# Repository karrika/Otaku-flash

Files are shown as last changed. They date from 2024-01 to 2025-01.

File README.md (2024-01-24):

# Otaku-flash
A single game flash card for Atari 2600, Atari 7800 and Atari 2600+

The logic in this card is based on Raspberrypi Pico
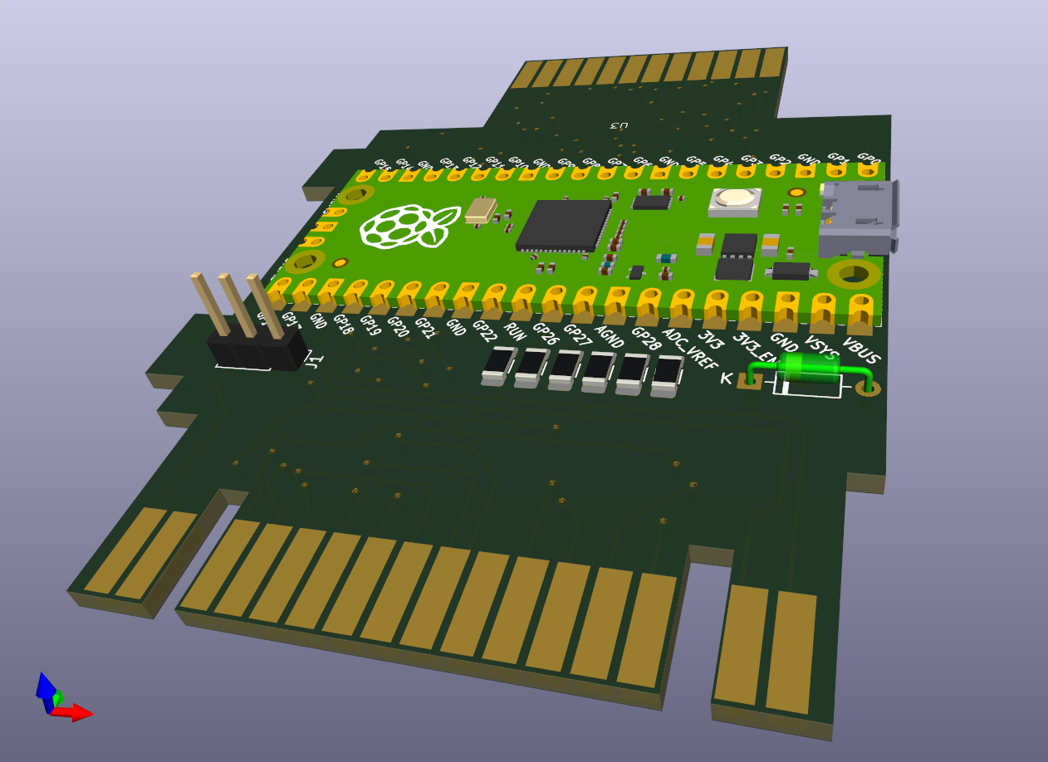
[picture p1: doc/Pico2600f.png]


The startup of the Pico is too slow for a real Atari 7800. The way I
run the game is by:
- inserting the card when the power is off
- then I connect a powerbank to Pico's USB socket
- finally I power on the console
This allows the Pico to prepare everything before I power on
my Atari 7800 console. The schottky diode in the cart prevents the
powerbank to power on the console when the cart has power but the
console has not.

The new Atari 2600+ does not have a startup problem. But the Otaku cart
may draw too much current so I am also using the powerbank when the cart
is in the 2600+.

The cart has a 2600 connector and a 7800 connector. The 7800 connector can
be used for running all games. The 2600 connector only works for 2600 games.

Programming the cart:
- keep the button pressed while inserting the USB cable to the PC
- release the button
- drag a a game.uf2 file to the folder opened by the Otaku card

For converting a game into the uf2 format you need to install Raspberry Pico
tools with the SDK kit.

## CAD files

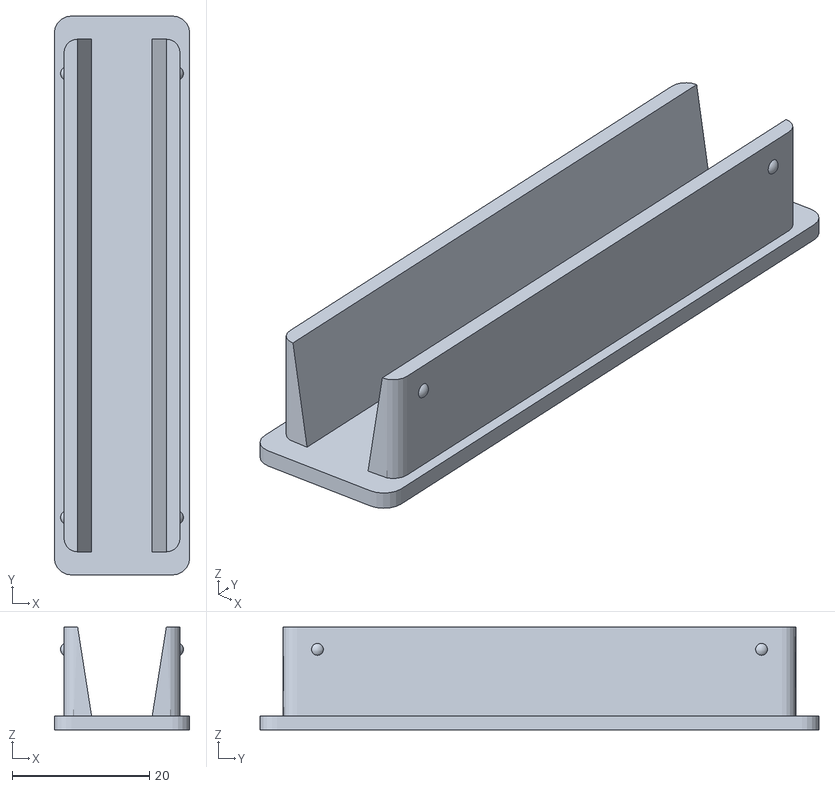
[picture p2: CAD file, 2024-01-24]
Otaku Flash Top2.stl
19.8 x 81.5 x 15.0

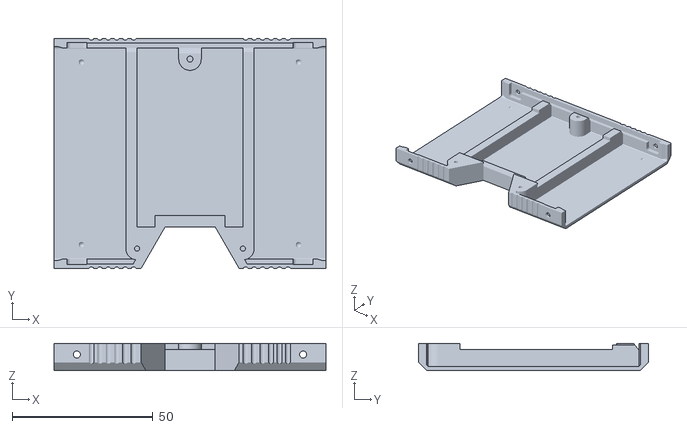
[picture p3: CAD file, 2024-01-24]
Otaku Flash Cart Bottom2.stl
96.5 x 81.5 x 9.75

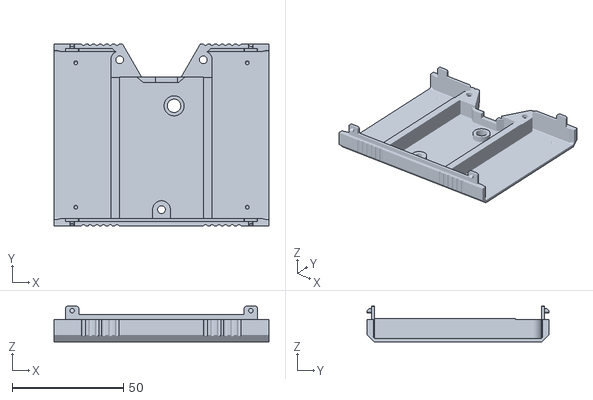
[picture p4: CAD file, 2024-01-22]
Otaku Flash Cart Top.stl
96.5 x 81.5 x 16.0

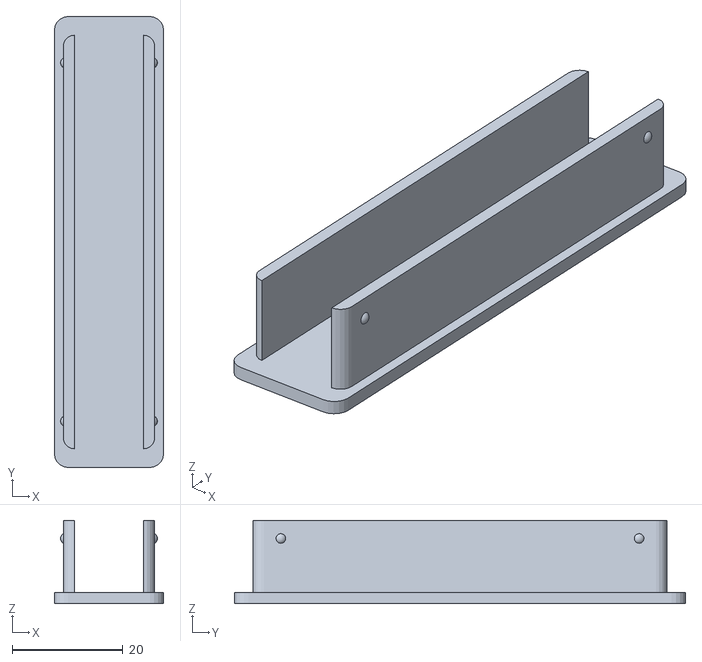
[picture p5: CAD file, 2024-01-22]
Otaku Flash Cart Cover.stl
19.8 x 81.5 x 15.0

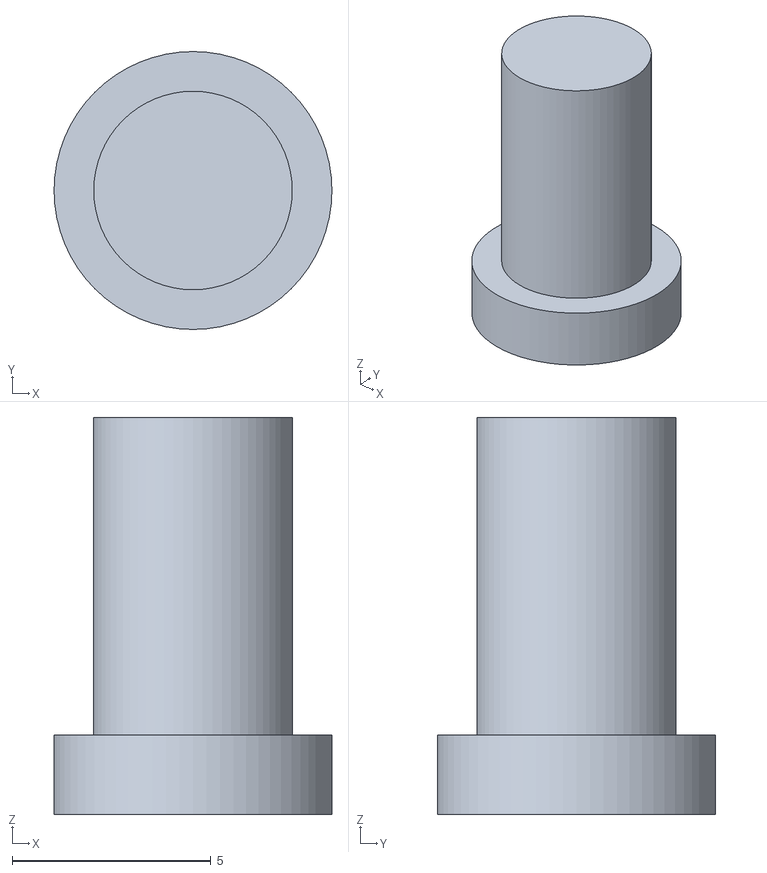
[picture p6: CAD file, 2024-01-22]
Otaku Flash Cart Button.stl
7.00 x 7.00 x 10.0

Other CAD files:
Otaku Flash Cart Bottom.stl
Otaku.blend

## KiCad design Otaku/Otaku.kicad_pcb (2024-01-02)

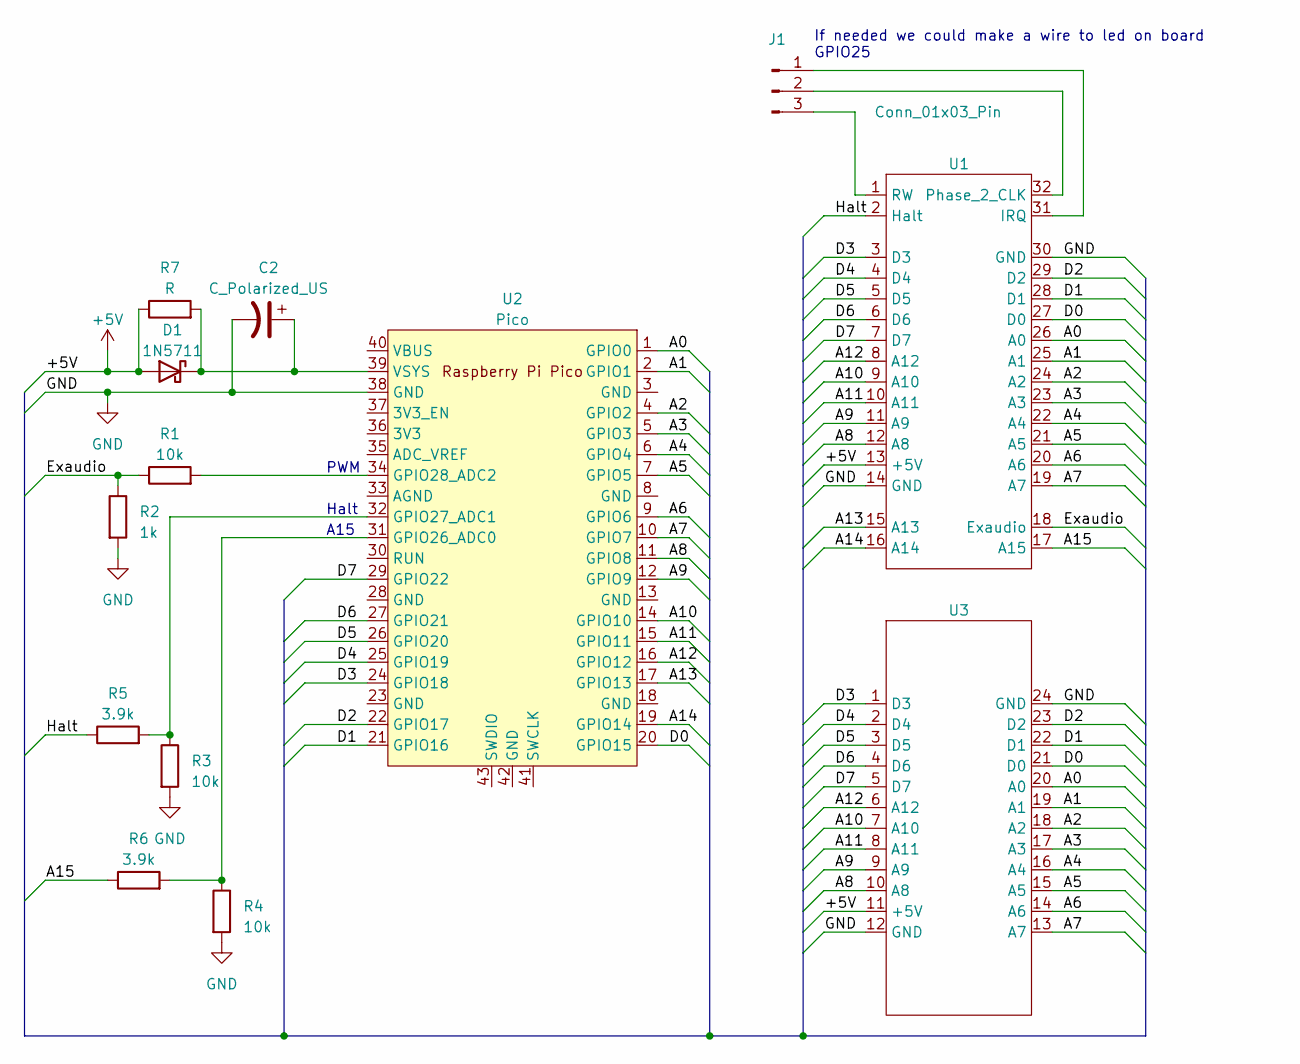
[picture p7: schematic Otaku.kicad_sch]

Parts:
C2: C_Polarized_US; CP_Axial_L10.0mm_D4.5mm_P15.00mm_Horizontal
D1: 1N5711; D_DO-35_SOD27_P7.62mm_Horizontal
J1: Conn_01x03_Pin; PinHeader_1x03_P2.54mm_Vertical
R1, R3, R4: 10k; R_1206_3216Metric_Pad1.30x1.75mm_HandSolder
R2: 1k; R_1206_3216Metric_Pad1.30x1.75mm_HandSolder
R5, R6: 3.9k; R_1206_3216Metric_Pad1.30x1.75mm_HandSolder
R7: R; R_1206_3216Metric_Pad1.30x1.75mm_HandSolder
U1: A7800
U2: Pico; RPi_Pico_SMD_TH
U3: A2600

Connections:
+5V: D1.2 (A), R7.1, U1.13 (+5V), U3.11 (+5V)
/A0: U1.26 (A0), U2.1 (GPIO0), U3.20 (A0)
/A1: U1.25 (A1), U2.2 (GPIO1), U3.19 (A1)
/A2: U1.24 (A2), U2.4 (GPIO2), U3.18 (A2)
/A3: U1.23 (A3), U2.5 (GPIO3), U3.17 (A3)
/A4: U1.22 (A4), U2.6 (GPIO4), U3.16 (A4)
/A5: U1.21 (A5), U2.7 (GPIO5), U3.15 (A5)
/A6: U1.20 (A6), U2.9 (GPIO6), U3.14 (A6)
/A7: U1.19 (A7), U2.10 (GPIO7), U3.13 (A7)
/A8: U1.12 (A8), U2.11 (GPIO8), U3.10 (A8)
/A9: U1.11 (A9), U2.12 (GPIO9), U3.9 (A9)
/A10: U1.9 (A10), U2.14 (GPIO10), U3.7 (A10)
/A11: U1.10 (A11), U2.15 (GPIO11), U3.8 (A11)
/A12: U1.8 (A12), U2.16 (GPIO12), U3.6 (A12)
/A13: U1.15 (A13), U2.17 (GPIO13)
/A14: U1.16 (A14), U2.19 (GPIO14)
/A15: R6.1, U1.17 (A15)
/D0: U1.27 (D0), U2.20 (GPIO15), U3.21 (D0)
/D1: U1.28 (D1), U2.21 (GPIO16), U3.22 (D1)
/D2: U1.29 (D2), U2.22 (GPIO17), U3.23 (D2)
/D3: U1.3 (D3), U2.24 (GPIO18), U3.1 (D3)
/D4: U1.4 (D4), U2.25 (GPIO19), U3.2 (D4)
/D5: U1.5 (D5), U2.26 (GPIO20), U3.3 (D5)
/D6: U1.6 (D6), U2.27 (GPIO21), U3.4 (D6)
/D7: U1.7 (D7), U2.29 (GPIO22), U3.5 (D7)
/Exaudio: R1.1, R2.1, U1.18 (Exaudio)
/Halt: R5.1, U1.2 (Halt)
GND: C2.2, R2.2, R3.2, R4.2, U1.14 (GND), U1.30 (GND), U2.38 (GND), U3.12 (GND), U3.24 (GND)
unnamed: C2.1, D1.1 (K), R7.2, U2.39 (VSYS)
unnamed: J1.1, U1.31 (IRQ)
unnamed: J1.2, U1.32 (Phase_2_CLK)
unnamed: J1.3, U1.1 (RW)
unnamed: R4.1, R6.2, U2.31 (GPIO26_ADC0)
unnamed: R3.1, R5.2, U2.32 (GPIO27_ADC1)
unnamed: R1.2, U2.34 (GPIO28_ADC2)

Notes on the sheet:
PWM
A15
Halt
If needed we could make a wire to led on board GPIO25

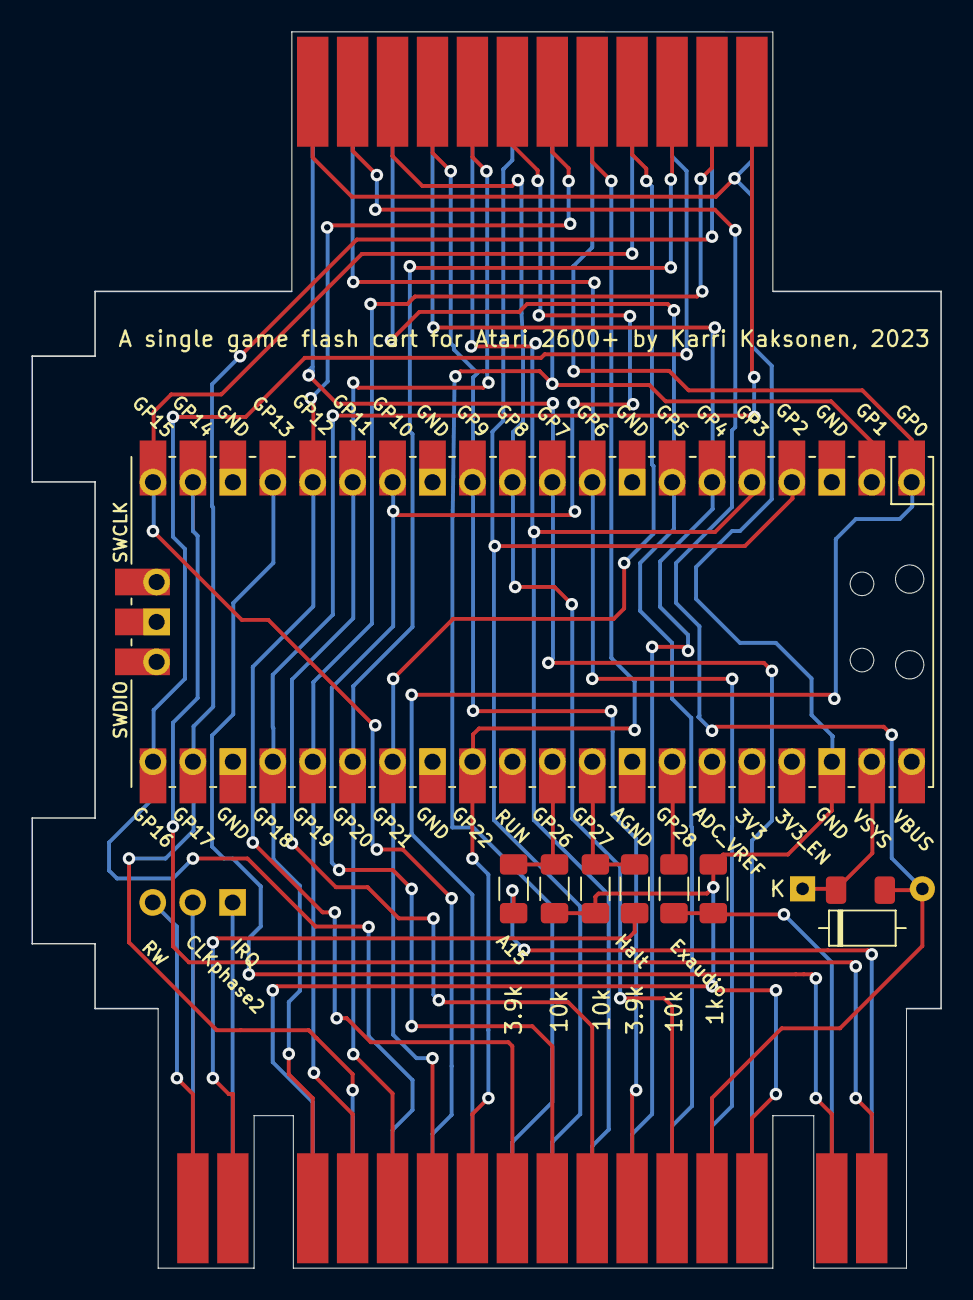
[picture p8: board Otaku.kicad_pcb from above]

Board: 2 copper layers, 57.8 x 78.6 mm, 12 parts (0 on the bottom side), 35 nets.

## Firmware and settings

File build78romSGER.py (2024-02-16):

import sys

class rom:
    def __init__(self, fname):
        with open(fname, 'rb') as f:
            self.raw = f.read()
            if len(self.raw) % 1024 == 128:
                self.data = self.raw[128:]
            else:
                self.data = self.raw

    def writedata(self, f):
        code = '''
/*
* Otaku-flash
* Simulate an SuperGame with EXRAM Atari 7800 ROM chip with a
* Raspberry Pi Pico.
*
* Last 16k bank 7 at C000 is fixed
* There is also a 16k RAM bank at 4000
* a write to area 8000-BFFF chooses the 16k bank for the 8000 area
*
* Karri Kaksonen, 2024
* based on work by
* Nick Bild 2021
*/

#include "pico/stdlib.h"
#include "hardware/clocks.h"
#include "hardware/vreg.h"
#include "pin_definitions.h"
#include <string.h>

'''
        f.write(code)
        f.write('#define ROM_SIZE ' + "0x{:x}".format(len(self.data)) + '\n')
        f.write('#define BANKS ' + "0x{:x}".format(int(len(self.data) / 16384)) + '\n')
        f.write('\n')
        f.write('const uint8_t game_contents[ROM_SIZE] __attribute__ ((aligned(ROM_SIZE))) = {\n')
        for i in range(0, len(self.data), 8):
            f.write('    ')
            for j in range(7):
                f.write("0x{:02x}".format(self.data[i + j]) + ', ')
            if i + 7 < len(self.data) - 1:
                f.write("0x{:02x}".format(self.data[i + 7]) + ',\n')
            else:
                f.write("0x{:02x}".format(self.data[i + 7]))
        f.write('};\n')
        f.write('\n')
        if len(self.data) <= 128 * 1024:
            code = '''
uint8_t ram_contents[ROM_SIZE] __attribute__ ((aligned(0x10000))) = {};
uint8_t exram_contents[0x4000] __attribute__ ((aligned(0x100))) = {};

int main() {
    uint32_t rawaddr;
    uint32_t addr;
    uint32_t bank;
    uint8_t newbank;
    uint8_t rom_in_use;
    uint8_t readwrite;

    // Specify contents of emulated ROM.
    memcpy(ram_contents, game_contents, ROM_SIZE);
    rom_in_use = 1;
    // Set default bank
    bank = 0;

    // Set system clock speed.
    // 400 MHz
    vreg_set_voltage(VREG_VOLTAGE_1_30);
    set_sys_clock_pll(1600000000, 4, 1);
    
    // GPIO setup.
    gpio_init_mask(0xe7fffff);         // All pins.
    gpio_set_dir_in_masked(0xe007fff); // Address and RW pins.
    gpio_set_dir_out_masked(0x7f8000); // Data pins.
    gpio_set_function(A15, GPIO_FUNC_NULL);
    gpio_set_function(RW, GPIO_FUNC_NULL);
    
    // Continually check address lines and
    // put associated data on bus.
    while (true) {
        // Get address
        rawaddr = gpio_get_all();
        addr = rawaddr & 0x7fff;
        // Check for A15
        if (rawaddr & 0x4000000) {
            // Check for A14
            if (addr & 0x4000) {
                // Set the data on the bus for fixed bank 7
                gpio_put_masked(0x7f8000, ram_contents[addr + ROM_SIZE - 0x8000] << 15);
                rawaddr = gpio_get_all() & 0x6004000;
	        if (rawaddr == 0x6004000) {
                    // Read cycle
                    if (!rom_in_use) {
                        gpio_set_dir_out_masked(0x7f8000);
                        rom_in_use = 1;
                    }
                }
            } else {
                // Set the data on the bus for active bank
                gpio_put_masked(0x7f8000, ram_contents[addr + bank] << 15);
                // Check for RW
                rawaddr = gpio_get_all() & 0x6004000;
	        if (rawaddr == 0x6000000) {
                    // Read cycle
                    if (!rom_in_use) {
                        gpio_set_dir_out_masked(0x7f8000);
                        rom_in_use = 1;
                    }
                } else {
                    // Write cycle to ROM
                    rawaddr = gpio_get_all() & 0x6000000;
                    // Check for bankswitch
                    if (rawaddr == 0x4000000) {
                        // Bankswitching write
                        gpio_set_dir_in_masked(0x7f8000);
                        rawaddr = gpio_get_all();
                        newbank = (rawaddr >> 15) & 0xff;
                        if (newbank < BANKS) {
                            bank = newbank * 0x4000;
                        }
                        rom_in_use = 0;
                    }
                }
            }
        } else {
            rawaddr = gpio_get_all();
            // EXRAM at 0x4000
            if (rawaddr & 0x4000) {
                addr = rawaddr & 0x3fff;
                gpio_put_masked(0x7f8000, exram_contents[addr] << 15);
                rawaddr = gpio_get_all() & 0x6004000;
	        if (rawaddr == 0x2004000) {
                    // Read cycle
                    if (!rom_in_use) {
                        gpio_set_dir_out_masked(0x7f8000);
                        rom_in_use = 1;
                    }
                } else {
	            if (rawaddr == 0x0004000) {
                        // Write cycle
                        gpio_set_dir_in_masked(0x7f8000);
                        rawaddr = gpio_get_all();
                        exram_contents[rawaddr & 0x3fff] = (rawaddr >> 15) & 0xff;
                        rom_in_use = 0;
                    } else {
                        if (rom_in_use) {
                            gpio_set_dir_in_masked(0x7f8000);
                            rom_in_use = 0;
                        }
                    }
                }
            } else {
                if (rom_in_use) {
                    gpio_set_dir_in_masked(0x7f8000);
                    rom_in_use = 0;
                }
            }
        }
    }
}

'''
        else:
            code = '''
uint8_t exram_contents[0x4000] __attribute__ ((aligned(0x100))) = {};

int main() {
    uint32_t oldrawaddr;
    uint32_t rawaddr;
    uint32_t addr;
    uint32_t bank;
    uint8_t newbank;
    uint8_t rom_in_use;
    uint8_t readwrite;

    // Specify contents of emulated ROM.
    rom_in_use = 1;
    // Set default bank
    bank = 0;

    // Set system clock speed.
    // 400 MHz
    vreg_set_voltage(VREG_VOLTAGE_1_30);
    set_sys_clock_pll(1600000000, 4, 1);
    
    // GPIO setup.
    gpio_init_mask(0xe7fffff);         // All pins.
    gpio_set_dir_in_masked(0xe007fff); // Address and RW pins.
    gpio_set_dir_out_masked(0x7f8000); // Data pins.
    gpio_set_function(A15, GPIO_FUNC_NULL);
    gpio_set_function(RW, GPIO_FUNC_NULL);
    
    // Continually check address lines and
    // put associated data on bus.
    while (true) {
        // Get address
        rawaddr = gpio_get_all();
        addr = rawaddr & 0x7fff;
        // Check for A15
        if (rawaddr & 0x4000000) {
            // Check for A14
            if (addr & 0x4000) {
                // Set the data on the bus for fixed bank 7
                gpio_put_masked(0x7f8000, game_contents[addr + ROM_SIZE - 0x8000] << 15);
                rawaddr = gpio_get_all() & 0x6004000;
	        if (rawaddr == 0x6004000) {
                    // Read cycle
                    if (!rom_in_use) {
                        gpio_set_dir_out_masked(0x7f8000);
                        rom_in_use = 1;
                    }
                }
            } else {
                // Set the data on the bus for active bank
                gpio_put_masked(0x7f8000, game_contents[addr + bank] << 15);
                // Check for RW
                rawaddr = gpio_get_all() & 0x6004000;
	        if (rawaddr == 0x6000000) {
                    // Read cycle
                    if (!rom_in_use) {
                        gpio_set_dir_out_masked(0x7f8000);
                        rom_in_use = 1;
                    }
                } else {
                    // Write cycle to ROM
                    rawaddr = gpio_get_all() & 0x6000000;
                    // Check for bankswitch
                    if (rawaddr == 0x4000000) {
                        // Bankswitching write
                        gpio_set_dir_in_masked(0x7f8000);
                        rawaddr = gpio_get_all();
                        newbank = (rawaddr >> 15) & 0xff;
                        if (newbank < BANKS) {
                            bank = newbank * 0x4000;
                        }
                        rom_in_use = 0;
                    }
                }
            }
        } else {
            rawaddr = gpio_get_all();
            // EXRAM at 0x4000
            if (rawaddr & 0x4000) {
                addr = rawaddr & 0x3fff;
                gpio_put_masked(0x7f8000, exram_contents[addr] << 15);
                rawaddr = gpio_get_all() & 0x6004000;
	        if (rawaddr == 0x2004000) {
                    // Read cycle
                    if (!rom_in_use) {
                        gpio_set_dir_out_masked(0x7f8000);
                        rom_in_use = 1;
                    }
                } else {
	            if (rawaddr == 0x0004000) {
                        // Write cycle
                        gpio_set_dir_in_masked(0x7f8000);
                        rawaddr = gpio_get_all();
                        exram_contents[rawaddr & 0x3fff] = (rawaddr >> 15) & 0xff;
                        rom_in_use = 0;
                    } else {
                        if (rom_in_use) {
                            gpio_set_dir_in_masked(0x7f8000);
                            rom_in_use = 0;
                        }
                    }
                }
            } else {
                if (rom_in_use) {
                    gpio_set_dir_in_masked(0x7f8000);
                    rom_in_use = 0;
                }
            }
        }
    }
}

'''
        f.write(code)

if __name__ == '__main__':
    fname=str(sys.argv[len(sys.argv)-1])
    r = rom(fname)
    fname = 'rom.c'
    f = open(fname, 'w')
    r.writedata(f)
    f.close()

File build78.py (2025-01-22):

import sys
import subprocess
import build78rom8k
import build78rom16k
import build78rom32k
import build78rom48k
import build78romAB
import build78romSG
import build78romSGEF
import build78romSGER
import build78romSGERP450
import build78romSGERYMP450

class rom:
    def __init__(self, fname):
        self.fname = fname

    def carttype(self):
        self.type = b'Not supported'
        with open(self.fname, 'rb') as f:
            data = f.read()
        self.header = data[:128]
        self.version = self.header[0]
        print('Version:', self.version)
        self.name = str(self.header[17:49], 'utf-8')
        print('Name:', self.name)
        self.size = int.from_bytes(self.header[49:53], 'big')
        print('Size:', self.size)
        if self.size == 8192:
            self.type = b'8K'
        elif self.size == 16384:
            self.type = b'16K'
        elif self.size == 32768:
            self.type = b'32K'
        elif self.size == 49152:
            self.type = b'48K'
        self.CartType = []
        self.typeA = self.header[53]
        self.typeB = self.header[54]
        if self.typeB & 2:
            self.CartType.append('SUPER')
            self.type = b'SG'
        if self.typeB & 16:
            self.CartType.append('EXFIX')
            if self.type == b'SG':
                self.type = b'SGEF'
            else:
                self.type = b'Not supported'
        if self.typeB & 4:
            self.CartType.append('EXRAM')
            if self.type == b'SG':
                self.type = b'SGER'
            else:
                self.type = b'Not supported'
        if self.typeA & 32:
            self.CartType.append('BANKSET')
            self.type = b'Not supported'
        if self.typeA & 16:
            self.CartType.append('SOUPER')
            self.type = b'Not supported'
        if self.typeA & 2:
            self.CartType.append('ABSOLUTE')
            self.type = b'AB'
            print(self.type)
        if self.typeA & 64:
            self.CartType.append('EXRAM/M2')
            self.type = b'Not supported'
        if self.typeB & 8:
            self.CartType.append('EXROM')
            self.type = b'Not supported'
        if self.typeA & 128:
            self.CartType.append('POKEY @0800')
            self.type = b'Not supported'
        if self.typeA & 8:
            self.CartType.append('YM2151 @0461')
            if self.type == b'SGER':
                self.type = b'SGERYM'
            else:
                self.type = b'Not supported'
        if self.typeA & 4:
            self.CartType.append('POKEY @0440')
            self.type = b'Not supported'
        if self.typeA & 1:
            self.CartType.append('ACTIVISION')
            self.type = b'Not supported'
        if self.typeB & 128:
            self.CartType.append('EXRAM/A8')
            self.type = b'Not supported'
        if self.typeB & 64:
            self.CartType.append('POKEY @0450')
            if self.type == b'SGER':
                self.type = b'SGERP450'
            elif self.type == b'SGERYM':
                self.type = b'SGERYMP450'
            else:
                self.type = b'Not supported'
        if self.typeB & 32:
            self.CartType.append('EXRAM/X2')
            self.type = b'Not supported'
        if self.typeB & 1:
            self.CartType.append('POKEYU@4000')
            self.type = b'Not supported'
        print('Cartridge type:', self.CartType)
        self.controller1 = self.header[55]
        if self.controller1 == 1:
            self.controller1 = 'ProLine'
        print('Controller 1:', self.controller1)
        self.controller2 = self.header[56]
        if self.controller2 == 1:
            self.controller2 = 'ProLine'
        print('Controller 2:', self.controller2)
        self.video = self.header[57]
        if self.video & 2 != 0:
            self.blending = 'Composite blending'
            print(self.blending)
        if self.video & 1 == 0:
            self.video = 'NTSC'
        else:
            self.video = 'PAL'
        print(self.video)
        self.saves = self.header[58]
        if self.saves & 1 != 0:
            print('High Score cartridge')
        if self.saves & 2 != 0:
            print('SaveKey or AtariVox')
        self.irqs = self.header[63]
        if self.irqs != 0:
            print('IRQ', self.irqs)
            self.type = b'Not supported'
        self.slotdevice = self.header[64]
        if self.slotdevice != 0:
            print('Slot device:', self.slotdevice)
            if self.type == b'AB':
                pass
            elif self.type == b'SGEF':
                pass
            elif self.type == b'SGER':
                pass
            elif self.type == b'SGERP450':
                pass
            elif self.type == b'SGERYMP450':
                pass
            else:
                self.type = b'Not supported'

    def createrom(self):
        self.carttype()
        if self.type == b'8K':
            r = build78rom8k.rom(self.fname)
            fname = 'rom.c'
            f = open(fname, 'w')
            r.writedata(f)
            f.close()
        elif self.type == b'16K':
            r = build78rom16k.rom(self.fname)
            fname = 'rom.c'
            f = open(fname, 'w')
            r.writedata(f)
            f.close()
        elif self.type == b'32K':
            r = build78rom32k.rom(self.fname)
            fname = 'rom.c'
            f = open(fname, 'w')
            r.writedata(f)
            f.close()
        elif self.type == b'48K':
            r = build78rom48k.rom(self.fname)
            fname = 'rom.c'
            f = open(fname, 'w')
            r.writedata(f)
            f.close()
        elif self.type == b'AB':
            r = build78romAB.rom(self.fname)
            fname = 'rom.c'
            f = open(fname, 'w')
            r.writedata(f)
            f.close()
        elif self.type == b'SG':
            r = build78romSG.rom(self.fname)
            fname = 'rom.c'
            f = open(fname, 'w')
            r.writedata(f)
            f.close()
        elif self.type == b'SGEF':
            r = build78romSGEF.rom(self.fname)
            fname = 'rom.c'
            f = open(fname, 'w')
            r.writedata(f)
            f.close()
        elif self.type == b'SGER':
            r = build78romSGER.rom(self.fname)
            fname = 'rom.c'
            f = open(fname, 'w')
            r.writedata(f)
            f.close()
        elif self.type == b'SGERP450':
            r = build78romSGERP450.rom(self.fname)
            fname = 'rom.c'
            f = open(fname, 'w')
            r.writedata(f)
            f.close()
        elif self.type == b'SGERYMP450':
            r = build78romSGERYMP450.rom(self.fname)
            fname = 'rom.c'
            f = open(fname, 'w')
            r.writedata(f)
            f.close()
        else:
            print(self.type, 'not supported, yet')
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

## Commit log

2024-01-02 Add KiCad 7 card design called Otaku
    [Otaku.kicad_pcb, Otaku.kicad_sch]
2024-01-04 Add enclosure Blender model
    [Otaku.blend]
2024-01-04 Add preliminary 3D printer files for the enclosure
    [OtakuBottom.stl, OtakuEnd.stl, OtakuTop.stl]
2024-01-04 Update case
    [Otaku.blend, OtakuBottom.stl, OtakuEnd.stl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]
2024-01-04 Fix OtakuEnd
    [Otaku.blend, OtakuEnd.stl]
2024-01-15 Initialize GPIO25 as input for new RW pin
2024-01-18 Add HALT pin
2024-01-21 Fix bankswitching for SC carts
    [build26romF8SC.py]
2024-01-22 New cart cover design
    [Otaku Flash Cart Bottom.stl, Otaku Flash Cart Button.stl, Otaku Flash Cart Cover.stl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]
2024-01-24 Remove obsolete files
    [OtakuBottom.stl, OtakuEnd.stl, OtakuTop.stl]
2024-01-24 Slightly modified top and screw holes
    [Otaku.blend]
2024-01-24 Make top a bit wider and stronger. Make screw holes on bottom smaller.
    [Otaku Flash Cart Bottom2.stl, Otaku Flash Top2.stl]
